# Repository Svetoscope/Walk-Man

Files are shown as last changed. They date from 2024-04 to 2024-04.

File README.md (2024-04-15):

# Walk-Man
## Projet S4
### Goal 
As part of a university project, the team Les Ti'namis set out to create a bipedal robot. This robot was intended to be capable of walking a distance of at least one meter, to have an interface for applying certain commands to the robot's operation, and to use only one motor per leg and for the balancing system.



In this GitHub repository, users will have access to the CAD files of all the parts used, as well as those related to the assemblies, while also being able to add their technical drawings. Additionally, there will be the codes used to program the activation of the motors and their interaction via an interface. The sections below briefly elaborate on the content available to the public.
### Global architecture

The preceding figure illustrates all the modules present in the project while demonstrating their interactions. To summarize, the user first selects an option from the interface. Depending on the chosen option, an instruction is then sent to an OpenRB via a computer displaying the interface. Following this instruction, the OpenRB sends a power command to one of the motors, which executes the movement of one of the legs or the inverse pendulum. The movement of a leg simply initiates a stride, allowing the robot to take a step forward. The activation of the inverse pendulum, on the other hand, moves a mass supported by a shaft from one side to the other of the robot to shift its center of mass. This functionality represents our balancing system, which aims to maintain the robot's balance. Once the movement is completed, feedback regarding the state of the robot is then sent to the interface from the OpenRB, which is awaiting a new instruction.

### CAD
The file WalkMan_CAD contains all the CAD files produced for the complete fabrication of the robot. The current biped consists of three main parts: the legs, the pelvis, and the torso. The parts used in assembling these components are listed in separate files by their names. Some parts are machined products sourced from large suppliers, such as McMaster. To differentiate these, parts with names in CAPITAL LETTERS are original creations of the team (often made of 3D printer plastic).

### OpenRB
The file s4_cpp contains all the code implemented in the OpenRB in C++. It is dedicated to the motors and movement of the associated legs, as well as the movement of the inverse pendulum. It is well-commented and easy to understand and use.

### Arduino IDE setup
To run and upload this code to an OpenRb-150 from the Arduino IDE you will need to first add the board and library on your Aruino IDE.
Please refer to the OpenRb-150 from ROBOTIS e-manual for all the instuction : https://emanual.robotis.com/docs/en/parts/controller/openrb-150/#development-environment.

### Interface
The file s4_python contains the Python codes related to the interface and serial port communication with the OpenRB. It is also well-commented and easy to understand. The file to run is the file entitled main.py. The figure below shows the appearance of the interface once the code is executed.


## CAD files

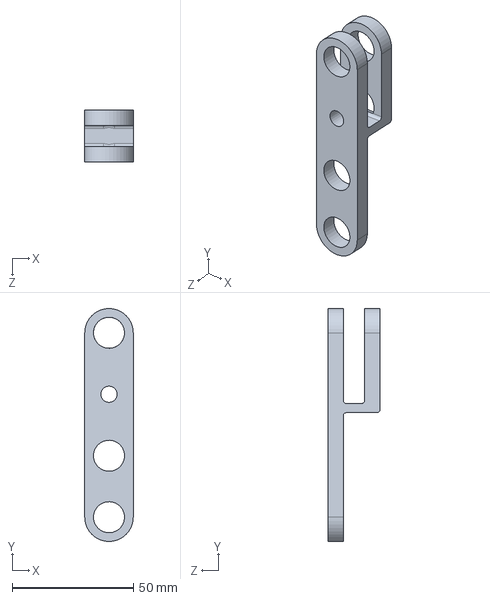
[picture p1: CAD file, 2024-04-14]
Walkman_CAD/LEGS/FEMUR.SLDPRT
20.1 x 96.3 x 21.6 mm

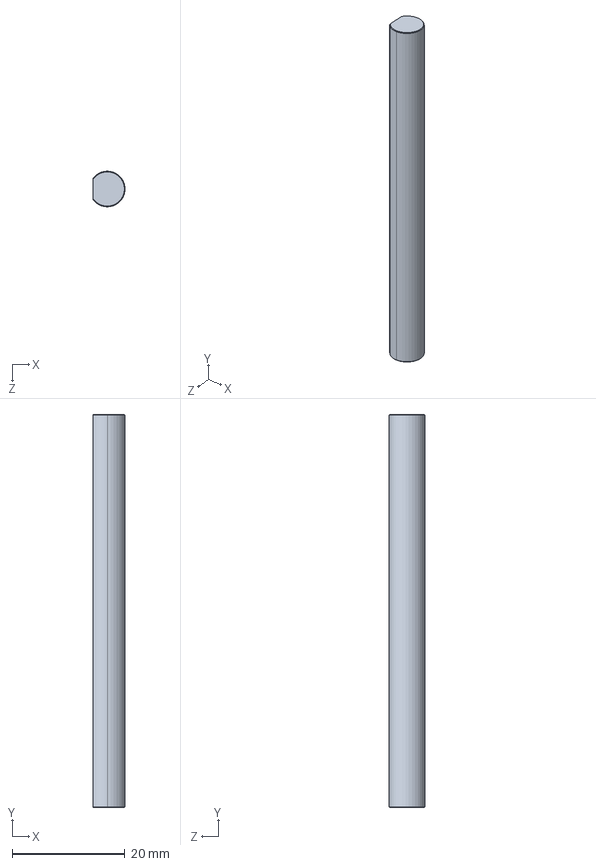
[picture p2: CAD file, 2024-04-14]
Walkman_CAD/PELVIS/D-Profile Rotary Shaft 2-75.SLDPRT
5.70 x 69.8 x 6.34 mm

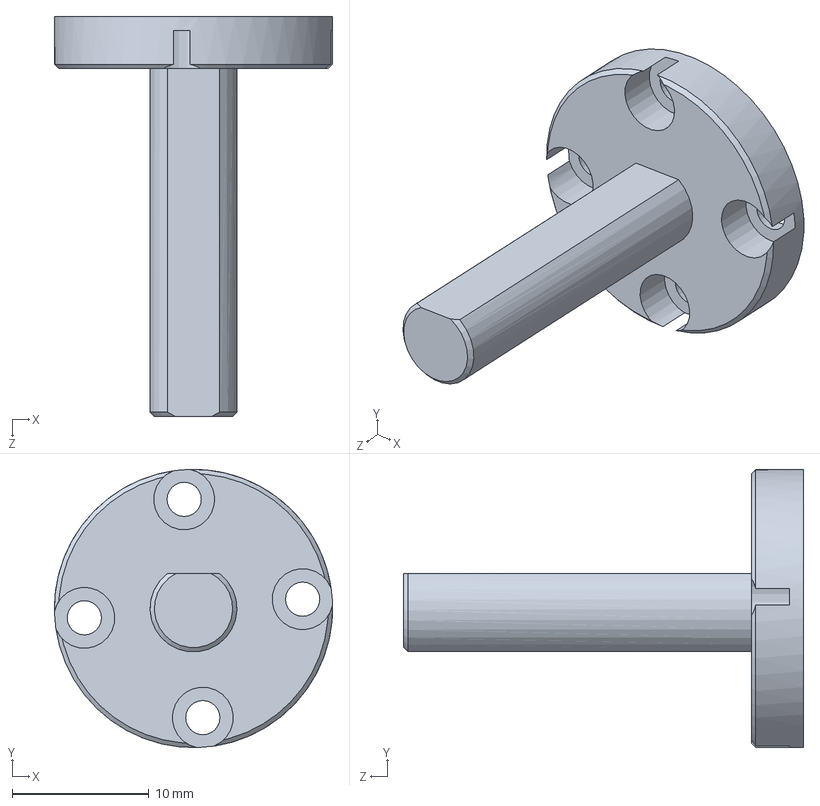
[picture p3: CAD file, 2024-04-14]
Walkman_CAD/PELVIS/MOTOR_COUPLER_W250.SLDPRT
20.3 x 20.3 x 29.2 mm

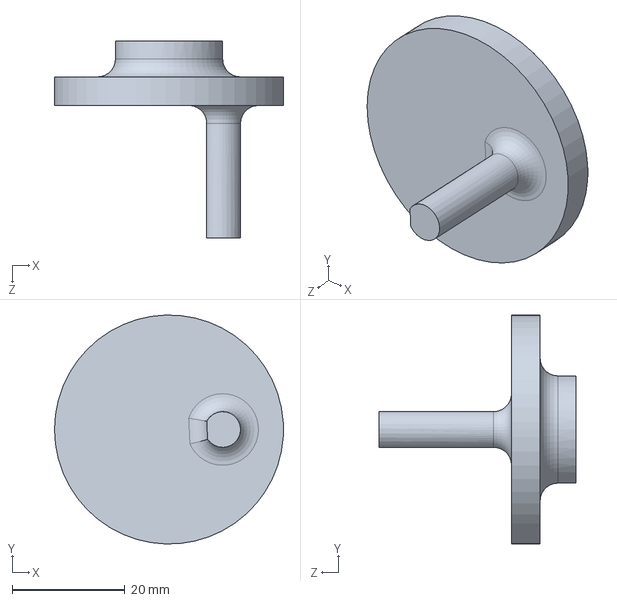
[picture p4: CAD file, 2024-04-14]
Walkman_CAD/LEGS/CRANKPIN.SLDPRT
40.6 x 40.6 x 34.9 mm

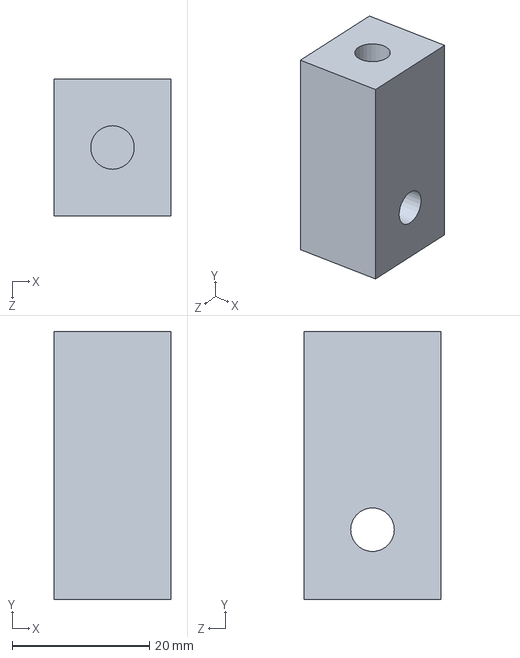
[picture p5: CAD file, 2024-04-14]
Walkman_CAD/WAIST/PENDULUM_SUPPORT.SLDPRT
17.0 x 39.0 x 20.0 mm

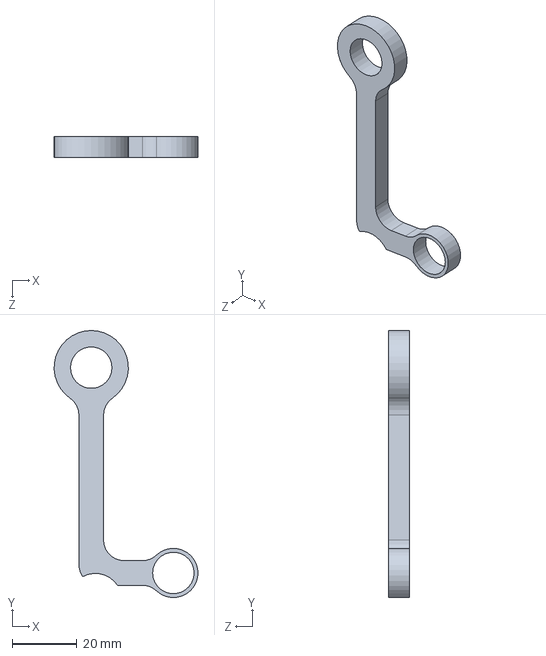
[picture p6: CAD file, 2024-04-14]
Walkman_CAD/LEGS/ISCHIO.SLDPRT
44.4 x 82.6 x 6.35 mm

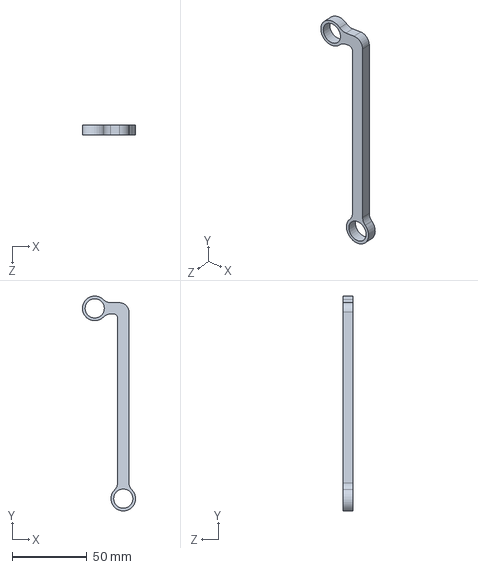
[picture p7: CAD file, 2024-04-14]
Walkman_CAD/LEGS/PERONE.SLDPRT
35.5 x 143.5 x 6.35 mm

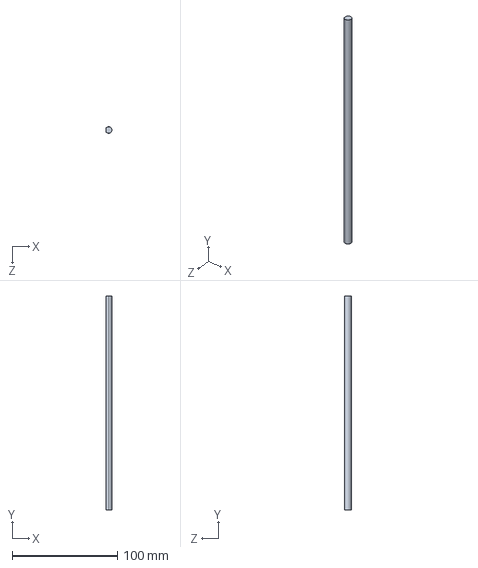
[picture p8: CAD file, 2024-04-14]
Walkman_CAD/PELVIS/D-Profile Rotary Shaft 8in.SLDPRT
5.72 x 203.2 x 6.34 mm

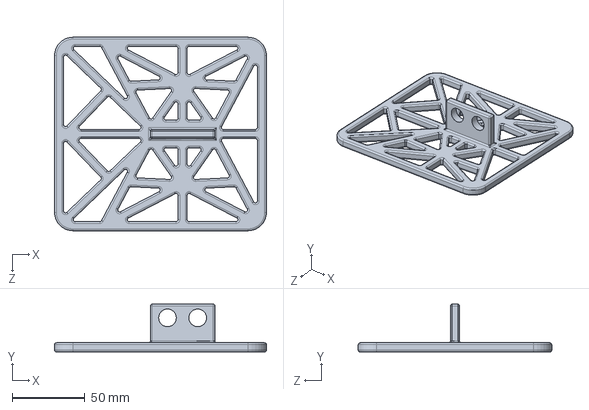
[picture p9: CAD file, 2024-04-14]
Walkman_CAD/LEGS/FEET.SLDPRT
146.1 x 33.0 x 133.4 mm

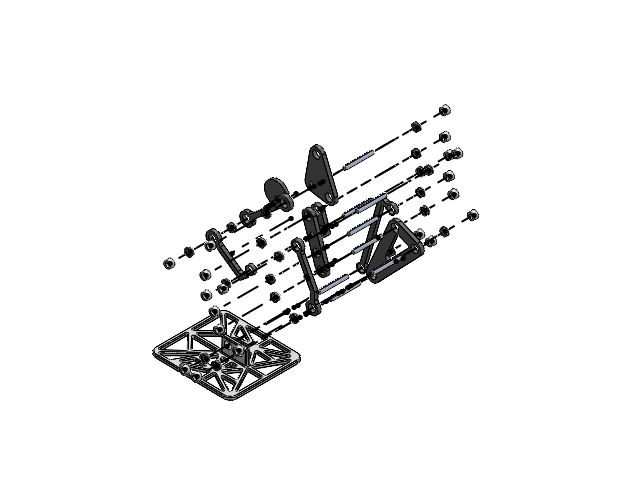
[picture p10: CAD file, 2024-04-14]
Walkman_CAD/LEGS/RIGHT_LEG.SLDASM
CRANKPIN
KNEECAP
PERONE
QUADRICEP
THIGH
TIBIA
ISCHIO
FEMUR
FEET
Stainless Steel Ball Bearing x 20
Set Screw Shaft Collar x 19
D-Profile Rotary Shaft 2in x 8

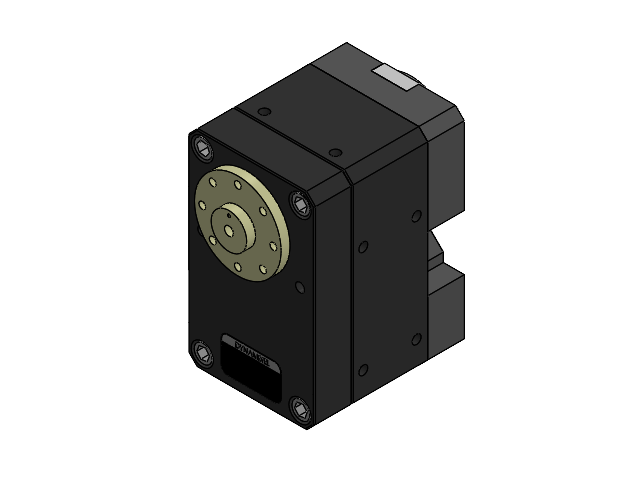
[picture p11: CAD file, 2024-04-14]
Walkman_CAD/WAIST/XM430-W350-R.SLDASM
Part 1.step
Part 2.step
Part 3.step
Part 4.step
Part 5.step
Part 6.step
Part 7.step
Part 8.step
Part 9.step
Part 10.step
Part 11.step
Part 12.step
Part 13.step
Part 14.step
Part 15.step
Part 16.step

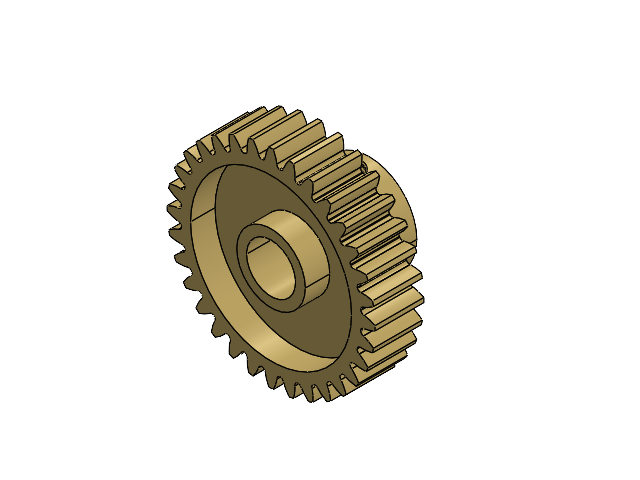
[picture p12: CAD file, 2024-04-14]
Walkman_CAD/PELVIS/32 Bore Gear 32 Pitch Shaft Mount Pinion Gears.SLDASM
615254_Gear Blank.STEP
632134_91375A436.STEP

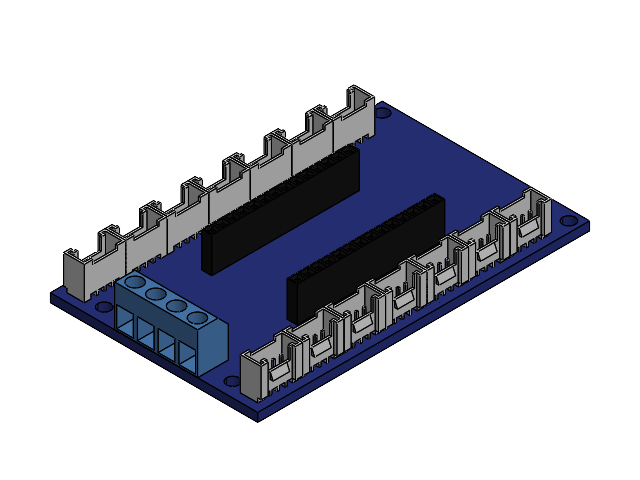
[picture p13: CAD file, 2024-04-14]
Walkman_CAD/WAIST/arduino-mkr-connector-carrier.SLDASM
Connecteur-grove.step x 14
pcb.step
14-pin-header.step x 2
terminal-block.step

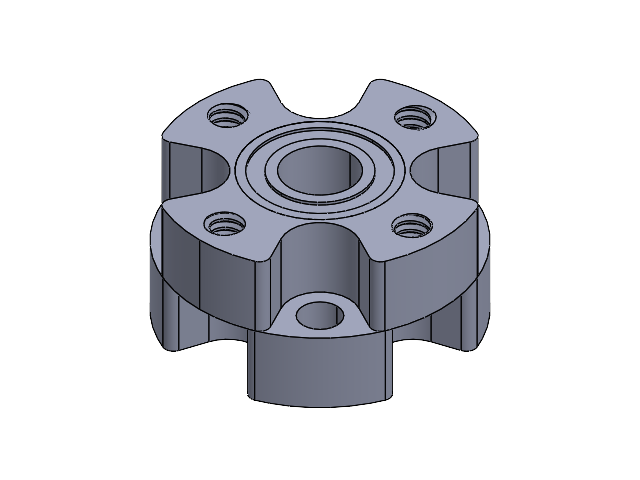
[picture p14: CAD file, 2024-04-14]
Walkman_CAD/WAIST/Dual Ball Bearing Hub.SLDASM
Dual Ball Bearing Hub 2
Dual Ball Bearing Hub 1 x 2

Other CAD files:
Walkman_CAD/PELVIS/XL430_W250_T.SLDASM
Walkman_CAD/WAIST/MPU-9250.SLDASM
Walkman_CAD/WAIST/Dual Ball Bearing Hub 2.SLDPRT
Walkman_CAD/3313N125_High-Strength Steel Threaded Rod.SLDPRT
Walkman_CAD/95462A029_Medium-Strength Steel Hex Nut.SLDPRT
Walkman_CAD/LEGS/D-Profile Rotary Shaft 2in.SLDPRT
Walkman_CAD/LEGS/KNEECAP.SLDPRT
Walkman_CAD/LEGS/QUADRICEP.SLDPRT
Walkman_CAD/LEGS/Set Screw Shaft Collar.SLDPRT
Walkman_CAD/LEGS/Stainless Steel Ball Bearing.SLDPRT
Walkman_CAD/LEGS/THIGH.SLDPRT
Walkman_CAD/LEGS/TIBIA.SLDPRT
Walkman_CAD/PELVIS/90480A007_Low-Strength Steel Hex Nut.SLDPRT
Walkman_CAD/PELVIS/ENGINE_SUPPORT_W250.SLDPRT
Walkman_CAD/PELVIS/MOTOR_COUPLER_W250.STL
Walkman_CAD/PELVIS/PELVIS.SLDPRT
Walkman_CAD/PELVIS/Set Screw Shaft Collar.SLDPRT
Walkman_CAD/PELVIS/Stainless Steel Ball Bearing.SLDPRT
Walkman_CAD/PELVIS/Standoff.SLDPRT
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

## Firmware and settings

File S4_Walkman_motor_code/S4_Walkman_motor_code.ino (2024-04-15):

/*******************************************************************************
* Copyright 2016 ROBOTIS CO., LTD.
*
* Licensed under the Apache License, Version 2.0 (the "License");
* you may not use this file except in compliance with the License.
* You may obtain a copy of the License at
*
*     http://www.apache.org/licenses/LICENSE-2.0
*
* Unless required by applicable law or agreed to in writing, software
* distributed under the License is distributed on an "AS IS" BASIS,
* WITHOUT WARRANTIES OR CONDITIONS OF ANY KIND, either express or implied.
* See the License for the specific language governing permissions and
* limitations under the License.
*******************************************************************************/

/** Please refer to each DYNAMIXEL eManual(http://emanual.robotis.com) for supported Operating Mode
 * Operating Mode
 *  1. OP_POSITION                (Position Mode in protocol2.0, Joint Mode in protocol1.0)
 *  2. OP_VELOCITY                (Velocity Mode in protocol2.0, Speed Mode in protocol1.0)
 *  3. OP_PWM                     (PWM Mode in protocol2.0)
 *  4. OP_EXTENDED_POSITION       (Extended Position Mode in protocol2.0, Multi-turn Mode(only MX series) in protocol1.0)
 *  5. OP_CURRENT                 (Current Mode in protocol2.0, Torque Mode(only MX64,MX106) in protocol1.0)
 *  6. OP_CURRENT_BASED_POSITION  (Current Based Postion Mode in protocol2.0 (except MX28, XL430))
 */


/*
  Message read from Pi: <(letter describing movement to do)>
  Feedback message (To Pi): <(current movement letter)>
  Possible letters for movements:
    W: Walking
    S: stand
    N: no movement
    F: feedback requested
    T: launch local test
*/


#include <Dynamixel2Arduino.h>

// Please modify it to suit your hardware.
#if defined(ARDUINO_AVR_UNO) || defined(ARDUINO_AVR_MEGA2560) // When using DynamixelShield
  #include <SoftwareSerial.h>
  SoftwareSerial soft_serial(7, 8); // DYNAMIXELShield UART RX/TX
  #define DXL_SERIAL   Serial
  #define DEBUG_SERIAL soft_serial
  const int DXL_DIR_PIN = 2; // DYNAMIXEL Shield DIR PIN
#elif defined(ARDUINO_SAM_DUE) // When using DynamixelShield
  #define DXL_SERIAL   Serial
  #define DEBUG_SERIAL SerialUSB
  const int DXL_DIR_PIN = 2; // DYNAMIXEL Shield DIR PIN
#elif defined(ARDUINO_SAM_ZERO) // When using DynamixelShield
  #define DXL_SERIAL   Serial1
  #define DEBUG_SERIAL SerialUSB
  const int DXL_DIR_PIN = 2; // DYNAMIXEL Shield DIR PIN
#elif defined(ARDUINO_OpenCM904) // When using official ROBOTIS board with DXL circuit.
  #define DXL_SERIAL   Serial3 //OpenCM9.04 EXP Board's DXL port Serial. (Serial1 for the DXL port on the OpenCM 9.04 board)
  #define DEBUG_SERIAL Serial
  const int DXL_DIR_PIN = 22; //OpenCM9.04 EXP Board's DIR PIN. (28 for the DXL port on the OpenCM 9.04 board)
#elif defined(ARDUINO_OpenCR) // When using official ROBOTIS board with DXL circuit.
  // For OpenCR, there is a DXL Power Enable pin, so you must initialize and control it.
  // Reference link : https://github.com/ROBOTIS-GIT/OpenCR/blob/master/arduino/opencr_arduino/opencr/libraries/DynamixelSDK/src/dynamixel_sdk/port_handler_arduino.cpp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
  #define DXL_SERIAL   Serial3
  #define DEBUG_SERIAL Serial
  const int DXL_DIR_PIN = 84; // OpenCR Board's DIR PIN.
#elif defined(ARDUINO_OpenRB)  // When using OpenRB-150
  //OpenRB does not require the DIR control pin.
  #define DXL_SERIAL Serial1
  #define DEBUG_SERIAL Serial
  const int DXL_DIR_PIN = -1;
#else // Other boards when using DynamixelShield
  #define DXL_SERIAL   Serial1
  #define DEBUG_SERIAL Serial
  const int DXL_DIR_PIN = 2; // DYNAMIXEL Shield DIR PIN
#endif

// Constant variables 
const uint8_t DXL_ID1 = 1; // ID of leg 1 motor
const uint8_t DXL_ID2 = 2; // ID of leg 2 motor
const uint8_t DXL_ID3 = 3; // ID of pendulum motor
const uint8_t SWITCH_LEG1 = 6; //pin number for limit switch on right leg
const uint8_t SWITCH_LEG2 = 7; //pin number for limit switch on left leg
const float HOME_DXL1 = 345; // Home position for DXL_ID1. To calibrate 
const float HOME_DXL2 = 2839; // Home position for DXL_ID2. To calibrate
const float DESIRED_SPEED = 60; // Desired speed for the motor in motion. Adjust to liking 
const float DXL_PROTOCOL_VERSION = 2.0;
const uint8_t MAXCHARS = 30; // Maximum amount of characters in moveQueue
const float LIMIT = 110; // Current limit for pendulum motor
const int PEND_LEG1 = 1;
const int PEND_LEG2 = 2;
const int INIT_POS = 3;

 
// Global variables
bool init_pos = true; // True until all motors have been initialised and are at home position
bool first = false; // True for the first cycle of loop only
bool leg1_walk = false; // True if leg 1 is ready to walk
bool leg2_walk = false; // True if leg 2 is ready to walk
bool readInProgress = false;
bool walking = false;
float dxl3_pos1 = 0; // Position of DXL_ID3 when the pendulum is on the side of leg 2. To calibrate
float dxl3_pos2 = 0; // Position of DXL_ID3 when the pendulum is on the side of leg 1. To calibrate
float dxl3_middle = 0; // Position of DXL_ID3 when pendulum is vertical 
float leg_speed = 0; // Speed of motors 1 and 2
char moveQueue[MAXCHARS];
char state = 'P'; // State of the robot
int queueLength = 0;
int counter = 0;


Dynamixel2Arduino dxl(DXL_SERIAL, DXL_DIR_PIN);

//This namespace is required to use Control table item names
using namespace ControlTableItem;

void setup() {
  // Use Serial to debug.
  DEBUG_SERIAL.begin(9600);

  Serial.begin(115200); // ***** 

  // Set Port baudrate to 57600bps. This has to match with DYNAMIXEL baudrate.
  dxl.begin(57600);
  // Set Port Protocol Version. This has to match with DYNAMIXEL protocol version.
  dxl.setPortProtocolVersion(DXL_PROTOCOL_VERSION);

  // Get DYNAMIXEL information
  dxl.ping(DXL_ID1);
  dxl.ping(DXL_ID2);
  dxl.ping(DXL_ID3);

  // Puts limit switches pins in input_pullup mode
  pinMode(SWITCH_LEG1, INPUT_PULLUP);
  pinMode(SWITCH_LEG2, INPUT_PULLUP);
}

void loop() {
  // Only does this function once
  if(init_pos){
    position_init(); // Sets motors to their home position
  }
  if(queueLength != 0){
    state = moveQueue[0];
    removeFirstInQueue();
    counter = 0;
  }

  switch(state){
    case 'P':
      // Stop the robot
      break;

    case 'A':
      // Do one complete cycle of walk at slow speed
      leg_speed = DESIRED_SPEED;
      pendulum_leg1();
      leg1_walking();
      delay(50);
      leg1_walking();
      pendulum_leg2();
      leg2_walking();
      delay(50);
      leg2_walking();
      break;

    case 'B':
      // Do one complete cycle of walk at medium speed
      leg_speed = DESIRED_SPEED + 20*1;
      pendulum_leg1();
      leg1_walking();
      delay(50);
      leg1_walking();
      pendulum_leg2();
      leg2_walking();
      delay(50);
      leg2_walking();
      break;

    case 'C':
      // Do one complete cycle of walk at fast speed
      leg_speed = DESIRED_SPEED + 20*2;
      pendulum_leg1();
      leg1_walking();
      delay(50);
      leg1_walking();
      pendulum_leg2();
      leg2_walking();
      delay(50);
      leg2_walking();
      break;

    case 'N':
      // Standing position is the position of initialization 
      leg_speed = DESIRED_SPEED;
      pendulum_leg1();
      leg1_walking();
      state = 'P';
      break;

    case 'T':
      // Launch test sequence
      doTest();
      break;

    default:
      break;
  }

  if(Serial.available()){
    readSerial();
  }
}

void position_init(){
  // Used to set the motors to their home position
  dxl.torqueOff(DXL_ID1);
  dxl.setOperatingMode(DXL_ID1, OP_POSITION); //Sets motor to position mode
  dxl.writeControlTableItem(PROFILE_VELOCITY, DXL_ID1, 60); // Sets maximum speed of motor
  dxl.torqueOn(DXL_ID1);
  // Sends motor to a certain position (home in this case)
  if(dxl.setGoalPosition(DXL_ID1, HOME_DXL1)){
    delay(1000);
  }

  dxl.torqueOff(DXL_ID2);
  dxl.setOperatingMode(DXL_ID2, OP_POSITION); // Sets motor to position mode
  dxl.writeControlTableItem(PROFILE_VELOCITY, DXL_ID2, 60); // Sets maximum speed of motor
  dxl.torqueOn(DXL_ID2);
  // Sends motor to a certain position (home in this case)
  if(dxl.setGoalPosition(DXL_ID2, HOME_DXL2)){
    delay(1000);
  }

  dxl.torqueOff(DXL_ID3);
  dxl.setOperatingMode(DXL_ID3, OP_VELOCITY); // Sets motor to velocity mode
  // Pendulum initialization if it's over leg 1
  if(digitalRead(SWITCH_LEG1) == LOW){
    dxl3_pos1 = dxl.getPresentPosition(DXL_ID3);
    while(digitalRead(SWITCH_LEG2) != LOW){
      if(dxl.getPresentCurrent(DXL_ID3) < LIMIT){
        dxl.torqueOn(DXL_ID3);
        dxl.setGoalVelocity(DXL_ID3, 20);
      }else{
        errorMessage(INIT_POS);
      }
    }
    dxl.torqueOff(DXL_ID3);
    dxl3_pos2 = dxl.getPresentPosition(DXL_ID3); // Used to find vertical position of pendulum
  }
  // Pendulum initialization if it's over leg 2
  else if(digitalRead(SWITCH_LEG2) == LOW){
    dxl3_pos2 = dxl.getPresentPosition(DXL_ID3);
    while(digitalRead(SWITCH_LEG1) != LOW){
      if(dxl.getPresentCurrent(DXL_ID3) < LIMIT){
        dxl.torqueOn(DXL_ID3);
        dxl.setGoalVelocity(DXL_ID3, -20);
      }else{
        errorMessage(INIT_POS);
      }
    }
    dxl.torqueOff(DXL_ID3);
    dxl3_pos1 = dxl.getPresentPosition(DXL_ID3); // Used to find vertical position of pendulum
  }
  else{
    dxl.torqueOff(DXL_ID3);
  }

  // Set motors to velocity mode 
  dxl.torqueOff(DXL_ID1);
  dxl.writeControlTableItem(PROFILE_VELOCITY, DXL_ID1, 1000);
  dxl.writeControlTableItem(VELOCITY_LIMIT, DXL_ID1, 100);
  dxl.setOperatingMode(DXL_ID1, OP_VELOCITY);
  dxl.torqueOn(DXL_ID1);

  dxl.torqueOff(DXL_ID2);
  dxl.writeControlTableItem(PROFILE_VELOCITY, DXL_ID2, 1000);
  dxl.writeControlTableItem(VELOCITY_LIMIT, DXL_ID2, 100);
  dxl.setOperatingMode(DXL_ID2, OP_VELOCITY);
  dxl.torqueOn(DXL_ID2);

  dxl.torqueOff(DXL_ID3);
  dxl.setOperatingMode(DXL_ID3, OP_VELOCITY);
  dxl.torqueOn(DXL_ID3);

  init_pos = false; // Disables this function
  DEBUG_SERIAL.println("end init");

  
  if(dxl3_pos1 < 0 || dxl3_pos2 < 0){
    dxl3_pos1 = dxl3_pos1 + 4095;
    dxl3_pos2 = dxl3_pos2 + 4095;
  }
  float ecart = dxl3_pos2-dxl3_pos1;
  // Finds the vertical position of pendulum
  if((int(ecart) % 2) == 0){
    dxl3_middle = ecart/2;
  }else{
    dxl3_middle = (ecart-1)/2;
  }
  counter++;
}

void leg1_walking(){
  DEBUG_SERIAL.println("leg1");
  // Used to complete the walking cycle of leg1
  first = true;
  walking = true;
  int pos_start;
  int pos_end;
  while(walking){
    if(first){
      pos_end = dxl.getPresentPosition(DXL_ID1) + 4095; // End position after one complete cycle
      first = false;
    }
    // End of cycle conditions
    if((dxl.getPresentPosition(DXL_ID1) > (pos_end - 100)) && (dxl.getPresentPosition(DXL_ID1) < (pos_end + 100))){
      dxl.setGoalVelocity(DXL_ID1, 0);
      walking = false;
      break;
    }
    dxl.torqueOn(DXL_ID1);
    dxl.setGoalVelocity(DXL_ID1, leg_speed);
  }
}

void leg2_walking(){
  DEBUG_SERIAL.println("leg2");
  // Used to complete the walking cycle of leg2
  first = true;
  walking = true;
  int pos_start;
  int pos_end;
  while(walking){
    if(first){
      pos_end = dxl.getPresentPosition(DXL_ID2) - 4095; // End position after one complete cycle
      first = false;
    }
    // End of cycle conditions
    if((dxl.getPresentPosition(DXL_ID2) > (pos_end - 100)) && (dxl.getPresentPosition(DXL_ID2) < (pos_end + 100))){
      //dxl.torqueOff(DXL_ID2);
      dxl.setGoalVelocity(DXL_ID2, 0);
      walking = false;
      break;
    }
    dxl.torqueOn(DXL_ID2);
    dxl.setGoalVelocity(DXL_ID2, -1*leg_speed); // Negative speed for counter clock wise rotation
  }
}

void pendulum_leg1(){
  DEBUG_SERIAL.println("pendulum1");
  if(digitalRead(6) == LOW){
    while(digitalRead(7) != LOW){
      if(dxl.getPresentCurrent(DXL_ID3) < LIMIT){ // Condition for current limit in motor
        dxl.torqueOn(DXL_ID3);
        dxl.setGoalVelocity(DXL_ID3, getPendulumSpeed(dxl.getPresentPosition(DXL_ID3))); // Speed of pendulum proportionnal to its position
      }else{
        errorMessage(PEND_LEG1);
      }

    }
    dxl.torqueOff(DXL_ID3);
  }
}

void pendulum_leg2(){
  // Used to place the pendulum over leg1
  DEBUG_SERIAL.println("pendulum2");
  if(digitalRead(7) == LOW){
    while(digitalRead(6) != LOW){
      if(dxl.getPresentCurrent(DXL_ID3) < LIMIT){ // Condition for current limit in pendulum
        dxl.torqueOn(DXL_ID3);
        dxl.setGoalVelocity(DXL_ID3, getPendulumSpeed(dxl.getPresentPosition(DXL_ID3)) * -1); // Speed of pendulum proportionnal to its position
      }else{
        errorMessage(PEND_LEG2);
      }
    }
    dxl.torqueOff(DXL_ID3);
  }
}

float getPendulumSpeed(float pos){
  // Returns a speed proportionnal to position that is in argument
  float speed = (abs(dxl3_middle - pos)/dxl3_middle + 1) * 20;
   
  return speed;
}

void addToQueue(char charac) {
  moveQueue[queueLength] = charac;
  queueLength++;
}

void readSerial(){
  char startMarker = '<';
  char endMarker = '>';
  char lastCharRead;
  char msgToSend[3] = {'<', 'N', '>'};

  while(Serial.available()){
    lastCharRead = Serial.read();
  
    if(readInProgress){
      if(lastCharRead != endMarker){
        
        if(lastCharRead == 'F'){
          msgToSend[1] = 'R';
          state = 'P';
        }else{
          msgToSend[1] = lastCharRead;
          addToQueue(lastCharRead);
          DEBUG_SERIAL.print("adding to queue: ");
          DEBUG_SERIAL.println(lastCharRead);
        }
        DEBUG_SERIAL.print("msg to send: ");
        DEBUG_SERIAL.println(msgToSend);
        Serial.println(msgToSend);
      } 
    }

    if(lastCharRead == startMarker){
      readInProgress = true;
    }
    if(lastCharRead == endMarker){
      break;
    }
  }
  readInProgress = false;
}

void removeFirstInQueue() {
  for(int i = 0; i < queueLength-1; i++){
    moveQueue[i] = moveQueue[i+1];
  }
  queueLength--;
  moveQueue[queueLength] = 'N';
}


void doTest(){

}

void errorMessage(int location){
  bool messageWritten = false;
  while(true){
    dxl.torqueOff(DXL_ID1);
    dxl.torqueOff(DXL_ID2);
    dxl.torqueOff(DXL_ID3);

    if(!messageWritten){
      switch(location){
        case PEND_LEG1:
          Serial.println("Motor 3 has reached the current limit during the pendulum for leg 1 movement (pendulum_leg1) and is now in emergency stop");
          messageWritten = true;
          break;

        case PEND_LEG2:
          Serial.println("Motor 3 has reached the current limit during the pendulum for leg 2 movement (pendulum_leg2) and is now in emergency stop");
          messageWritten = true;
          break;

        case INIT_POS:
          Serial.println("Motor 3 has reached the current limit during the initialization (position_init) and is now in emergency stop");
          messageWritten = true;
          break;

        default:
          break;
      }
    }

    if(Serial.available()){
      Serial.println("<E>");
    }
  }
}

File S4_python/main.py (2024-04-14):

import threading
import time
from queue import Queue
from ComArduino import ComArduino
from UserInterface import UserInterface
from PyQt5.QtWidgets import QApplication

# Define the Control class
class Control:
    def __init__(self):
        # Initialize ComArduino instance
        self.comArduino = ComArduino()
        # Start communication with Arduino or OpenRB
        self.comArduino.start()

    # Method to send a message to Arduino or OpenRB
    def send_message(self, message: str):
        """
        List of valid messages :
        <A> : Driving motors at speed 1
        <B> : Driving motors at speed 2
        <C> : Driving motors at speed 3
        <N> : Neutral state
        <P> : Parking robot
        <F> : Asking for feedback
        """
        self.comArduino.send_to_arduino(message)

    # Method to get the answer from Arduino or OpenRB
    def get_answer(self) -> str:
        """
        List of valid answers :
        <A> : Driving motors at speed 1
        <B> : Driving motors at speed 2
        <C> : Driving motors at speed 3
        <N> : Neutral state
        <P> : Parking robot
        <R> : Ready to start another sequence
        """
        return self.comArduino.msg_received
        

# Function to handle switch cases for Arduino or OpenRB answers
def msg_switch_case(arduino_answer) -> int:
    if arduino_answer == 'D1' or arduino_answer == 'D2' or arduino_answer == 'D3' or arduino_answer == 'N' or arduino_answer == 'P':
        # Wait for the sequence to be finished
        return 0
    elif arduino_answer == 'R':
        # Ready to start another sequence
        return 1
    else:
        # Error
        return -1

# Function to scan UI queue
def scan_ui_queue(self, my_queue):
    while True:
        if self.UI_queue.empty():
            break
        else:
            my_queue.put(self.UI_queue.get())

# Function to run the user interface
def run_user_interface(ui_closed_flag, ui_queue, ui_start_flag, ui_update_flag):
    # Initialization of the user interface
    app = QApplication([])
    window = UserInterface(ui_queue, ui_start_flag, ui_update_flag)
    window.show()
    app.exec_()
    ui_closed_flag.set()

# Main function
def main() -> None:
    # Create variables linked to the thread of the UI
    ui_queue = Queue()
    ui_update_flag = threading.Event()
    ui_start_flag = threading.Event()
    ui_closed_flag = threading.Event()
    ui_thread = threading.Thread(target=run_user_interface, args=(ui_closed_flag, ui_queue, ui_start_flag, ui_update_flag))
    ui_thread.start()

    # Initialize Control instance
    controller = Control()

    error_count = 0
    # INIT COM
    message = 'F'
    controller.send_message(message)
    print("Message sent : ", message)
    time.sleep(1)

    message = 'F'
    controller.send_message(message)
    print("Message sent : ", message)
    time.sleep(1)

    checked_answer_flag = False
    allow_new_command_flag = False
    last_walking_speed = ""
    keep_walking_flag = False

    while not ui_closed_flag.is_set():
        # print("Loop")
        if controller.comArduino.new_msg_flag:
            controller.comArduino.new_msg_flag = False
            answer = controller.get_answer()
            print("Arduino reply : ", answer)
            state = msg_switch_case(answer)
            checked_answer_flag = False

        if ui_start_flag.is_set() and not checked_answer_flag:
            checked_answer_flag = True
            allow_new_command_flag = True

            if message != 'F' and answer != message:  # Means last sequence asked didn't start
                error_count += 1
            else:
                # print('State : ', state)
                if state == 1:  # Ready to start another sequence
                    print('Ready to start another sequence')
                    error_count = 0
                    if ui_queue.empty() and keep_walking_flag:
                        print('Keep walking')
                        message = last_walking_speed
                        keep_walking_flag = False
                    else:
                        print('Wait new command')
                        message = ui_queue.get()
                    
                    ui_update_flag.set()
                    if message == 'A' or message == 'B' or message == 'C':
                        last_walking_speed = message
                        keep_walking_flag = True
                    else:
                        keep_walking_flag = False
                elif state == 0:  # Wait for the sequence to be finished
                    print('Wait for the sequence to be finished')
                    error_count = 0
                    message = 'F'
                else:
                    print('Invalid Arduino answer')
                    error_count += 1
                    message = 'F'

            if error_count > 3:
                break

        if ui_start_flag.is_set() and checked_answer_flag and allow_new_command_flag:
            controller.send_message(message)
            print("Message sent : ", message)
            allow_new_command_flag = False

        time.sleep(1)

    ui_thread.join()
    return


if __name__ == "__main__":
    main()

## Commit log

2024-04-02 Add files via upload
    Ajout des codes moteurs
2024-04-02 Supprimer les anciens fichiers
2024-04-06 Update s4_Walkman_code_moteur.ino
    Update with limit switch
